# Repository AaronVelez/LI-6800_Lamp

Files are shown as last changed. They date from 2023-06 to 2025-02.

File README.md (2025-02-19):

# Hardware, software and data repository associated with “Open-source LED lamp for the LI-6800 photosynthesis system” paper.

&nbsp;
## Description
This repository contains the hardware CAD files, electronic schematics, software and data associated with an open-source LED lamp for the LI-6800 photosynthesis system. The full details on the lamp design, construction and calibration can be found in the associated paper. The paper is currently under review by the editorial office of the [Applications in Plant Science](https://bsapubs.onlinelibrary.wiley.com/journal/21680450) journal from the [Botanical Society of America](https://cms.botany.org/home.html).

&nbsp;
## Releases
|  Release |  Description |  Release date |
|  --- | --- | --- |
|  v1.0.0-beta.0 |  State of the repository at paper submission |  28 / Sep / 2023 |
|  v1.0.0-beta.1 |  State of the repository at paper resubmission | 23 / Apr / 2024 |
|  v1.0.0 | State of the repository at paper publication | 19 / Feb / 2025 |

&nbsp;
## Hardware
The content of this section is released under a [CERN Open Hardware Licence Version 2 - Weakly Reciprocal variant](Hardware/LICENSE). It has the following contents:

- AutoCAD Inventor files directory. It contains the 3D files of all individual parts as well as the final assembly in AutoCAD Inventor format.
- Ready-to-Print STL files directory. It contains the 3D-printable parts in STL format.
- STEP files directory. It contains the 3D files of all individual parts in STEP format.
- COB-LED driver Schematics.pdf file. Detailed electronic schematics.

&nbsp;
## Software
The content of this section is released under a [GNU Lesser General Public License Version 3](Software/LISENSE.LESSER). It has the following contents:

- Lamp folder. Software directly related with the Lamp function
  - A-PPFD_Curve.py file. An LI-6800 background program (a script in python) that performs an A-PPFD curve automatically.
  - LI-6800 Lamp Config File. A custom LI-6800 configuration file.
  - Microcontroller_Main.py file. A python script run by the Lamp internal microcontroller board.
  - PAR_Ctrl.py and PAR_Ctrl_wFB.py files. Two LI-6800 background program (a script in python) that control the light intensity in response to the desired PPFD entered by a user.

- Tools folder. Software tools used during lamp calibration and/or characterization
  - Curve_Fit_Zener_Diode.py file. A python script needed in the Lamp temperature control calibration.
  - Zenner Diode Calibration_Data Template.xlsx file. A Microsoft Excel file that serves as a data template for the Curve_Fit_Zener_Diode.py file
  - Homogenity_Scan_LabVIEW_VIs folder. A collection of LabVIEW VIs used to control a CNC machine in order to sacan the leaf area illuminated by the lamo with the objective of measuring the light homogenity
  - Homogenity_Scan_Python. Scripts used to process the RAW data measured with the LabVEW VIs

&nbsp;
## Data

- A-PPDF_Curves folder. This section contains the gas exchange data associated with the paper in a format that follows the recommendations of [Ely *et al.* (2021)]( https://doi.org/10.1016/j.ecoinf.2021.101232). The file [LI-6800_Lamp_Data_Description.pdf](Data/LI-6800_Lamp_Data_Description.pdf) holds a detailed description of all shared data files.
- Homogenity_Scans folder. This section contains the RAW measurements of the homogenity scans performed with the CNC machine.

&nbsp;
## Troubleshooting
|  Problem |  Possible reason |  Solution |
|  --- | --- | --- |
|  Fan and COB-LED do not turn ON |  External power supply is not connected | Make sure the external, 24V power supply is connected to the back of the lamp housing. |
|  At the LI-6800 console, Lamp_T shows values unexpectedly high (e.g. >100 °C), and Lamp_T_TH-r shows values close to 0 kohms |  The microcontroller is not exciting the thermistor with the required 3.3V |  At the LI-6800 console, navigate to the Console User I/O and turn ON the 5V power supply (Power5) |
|  At the LI-6800 console, the Q<sub>amb_in</sub> PPFD value is higher than the value measured with an external quantum sensor  | The Photodiode multiplier needs calibration  | Calibrate the photodiode multiplier following instructions in Appendix 2 |
|  The COB-LED dimly glows even if the DAC1 voltage is set to 0V  |  The zero offset of the XTR110 chip is not properly adjusted  |  Adjust the zero offset of the XTR110 chip by following the instructions in Appendix 2  |

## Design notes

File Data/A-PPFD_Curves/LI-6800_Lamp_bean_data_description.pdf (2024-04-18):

# Open-source LED lamp for the LI-6800 photosynthesis system

### Summary

In this work, a cost-effective lamp compatible with the LI-6800 photosynthesis measuring system was developed. The lamp uses a LED, emitting white light with a color temperature similar to sunlight. To demonstrate the functionality of the lamp, measurements of the response of photosynthesis to irradiance were made using PINTO SALTILLO bean line in 2024. In addition, some photosynthetic parameters were estimated form these measurements according to Busch et al. (2024).

The data described in this text is available on:

https://github.com/AaronVelez/LI-6800_Lamp/tree/main/Data

### Data Files

Data files:
LI-6800_Lamp_Bean_AQ_curves.csv
LI-6800_Lamp_ Bean_AQ_fittedparams.csv LI-6800_Lamp_ Bean_AQ_curves_InstrumentOutput.csv

Methods and metadata files:
LI-6800_Lamp_ Bean_methods_AQcurves.csv LI-6800_Lamp_ Bean_methods_AQparams.csv
LI-6800_Lamp_ Bean_instrumentDetails.csv

Data and methods files are in the format according the recommendations of Ely et al. (2021), following the example of Rogers et al. (2019)

### Data characteristics

Location | Escuela Nacional de Estudios Superiores Unidad León, León, Guanajuato, México
Latitude | 21.04
Longitude | 101.67
Altitude | 1.787 m ASL
Date from | 2024-03-21
Date to | 2024-03-22

### Data dictionaries

LI-6800_Lamp_ Bean_AQ_curves.csv
Number of records: 50
Header | Format | Units | Definition
USDA_Species_Code | Alphanumeric string | - | Code to identify the plant species used in measurements according the USDA
Sample_ID | Alphanumeric string | - | Identifier used for each sample
Date | Integer | YYYYMMDD | Date of observations
Time | HH:MM:SS | HH:MM:SS | Time of observations, set to local time (UTC-6)
A | Float | μmol m-2 s-1 | CO2 assimilation rate per leaf area
Ci | Float | µmol mol⁻¹ | Intercellular CO₂ concentration
CO2_S | Float | µmol mol⁻¹ | CO₂ concentration in air inside chamber
Patm | Float | kPa | Atmospheric pressure
Qin | Float | μmol m-2 s-1 | In-chamber photosynthetic flux density (PPFD) incident on the leaf, quanta per area
RHs | Float | % | Relative humidity of air inside the chamber
Tleaf | Float | °C | Leaf surface temperature

LI-6800_Lamp_ Bean_AQ_fittedparams.csv
Number of records: 5
Header | Format | Units | Definition
USDA_Species_Code | Alphanumeric string | - | Code to identify the plant species used in measurements according the USDA
Sample_ID | Alphanumeric string | - | Identifier used for each sample
Date | Integer | YYYYMMDD | Date of observations
Phi_CO2 | Float | - | Quantum efficiency of CO2 assimilation
A_Sat | Float | μmol m-2 s-1 | Light saturated CO2 assimilation rate

Rd | Float | μmol m-2 s-1 | Dark respiration rate derived only from the light response curve
Theta | Float | - | Empirical curvature factor of the response of CO2 assimilation to the light
I_comp | Float | μmol m-2 s-1 | Light compensation point

LI-6800_Lamp_ Bean_AQ_curves_InstrumentOutput.csv
Number of records: 50
This file is the output file obtained from the LI-6800 photosynthesis measuring system. The user definitions constants and variables are only described in the following table. The rest of the definitions for the other variables can be obtained from the LI-6800 under Start Up > Data Dictionary.
Header | Format | Units | Definition
Lamp_PAR_Ctrl | Float | μmol m-2 s-1 | Lamp desired PAR setpoint
Lamp_T_Ctrl | Float | °C | Lamp temperature setpoint
Lamp_Qamb_in_Factor | Float | - | Lamp mismatch factor between Qamb_in and Lamp_PAR_Ctrl
Lamp_T_trinket_V_Ctrl | Float | V | Lamp input Trinket voltage
Lamp_T_DAC2_V_Ctrl | Float | V | Lamp output Li-6800 voltage from auxiliary channel 2
Lamp_T_TH-r | Float | kohms | Lamp thermistor resistance. Measurement ADC_CH1 to thermistor resistance
Lamp_T | Float | °C | Lamp temperature. Measurement thermistor temperature to thermistor resistance
Lamp_PAR_DAC1_Ctrl | Float | V | Lamp output Li-6800 voltage to obtain the desired PAR setpoint

Example Data Records:

LI-6800_Lamp_ Bean_AQ_curves.csv

LI-6800_Lamp_ Bean_AQ_fittedparams.csv

USDA_Species_Code | Sample_ID | Date | Time A | Ci | CO2_s Patm Qin | RHs
Tleaf
- | - | YYYYMMDD | HH:MM:SS | μmol m-2 s-1 μmol mol-1 | μmol mol-1 | kPa
μmol m-2 s-1 % | °C
PHVU Bean1 20240322 | 14:36:54 | -1.613576991 400.2670327 400.09 82.0933
-0.154137 | 56.98042611 25.0162
PHVU Bean1 20240322 | 14:48:09 | 0.948748533 376.0389014 400.03 82.0997
40.0629 | 59.65035529 25.0068
USDA_Species_Code | Sample_ID | Date | Phi_CO2 | A_sat Rd | Theta I_comp
- | - | YYYYMMDD | - | μmol m-2 s-1 μmol m-2 s-1 - | μmol m-2 s-1
PHVU Bean1 20240322 | 0.060596005 19.36587742 1.536771248 0.78112109
25.80142873

PHVU Bean2 20240321 0.053367097 20.55056813 1.426724917 0.867451499 26.98018061

LI-6800_Lamp_ Bean_AQ_curves_InstrumentOutput.csv

USDA_Species_Code | Sample_ID | obs | time | elapseddate | hhmmss | averaging
Lamp_PAR_Ctrl Lamp_T_Ctrl | Lamp_Qamb_in_Factor Lamp_T_trinket_V_Ctrl
Lamp_T_DAC2_V_Ctrl Lamp_T_TH-r Lamp_TLamp_PAR_DAC1_Ctrl TIME E
Emm A | Ca | Ci | Pci | Pca | gsw | gbw | gtw | gtc | Rabs
TleafEB TleafCnd | SVPleaf RHcham | VPcham | SVPcham | VPDleaf
LatHFlux | SenHFlux | NetTherm | EBSum Leak | LeakPctCorrFact
CorrFactPct | Fan | Qin | Qabs alpha convertS | K | Geometry
CustomTIME CO2_s CO2_r H2O_s H2O_r CO2_a H2O_a Flow | Pa | ΔPcham
Tair | Tleaf Tleaf2 Offset Offset2 Fan_speed | Qamb_in | Qamb_out
ΔCO2 CO2_s_d | CO2_r_d | ΔH2O CO2_b H2O_b e_s | e_r | Td_s
Td_r | time | hhmmss | co2_t h2o_t count co2_adjh2o_adj | co2_match
h2o_match | co2_at h2o_at co2_cv h2o_cv CO2_r:MN | CO2_r:SLP | CO2_r:SD
CO2_r:OK | CO2_s:MN | CO2_s:SLP | CO2_s:SD | CO2_s:OK | H2O_s:MN
H2O_s:SLP | H2O_s:SD | H2O_s:OK | Stable Total State Vflow VPchamber
abs_c_a | abs_c_b | abs_h_a | abs_h_b | Wc_s Wc_r Wco_s
Wco_r Ww_s Ww_r Wwo_s Wwo_r Flow_s_v | Flow_r_v | Tleaf_mv
Tleaf2_mv | Tleaf_j Tleaf2_j | Console_RH | Console_T | Console_H2O
Fan_% Flow_%Pump Tchp_pwm | Txchg_pwm | diag_20v | diag_5_4v
diag_12v | diag_5va | diag_3_3vf | AccCO2_soda CO2_hrs
AccH2O_des | AccH2O_hum ADC_CH1 | ADC_CH2 | ADC_CH3 | ADC_CH4
ADC_CH5 | ADC_CH6 | ADC_CH7 | ADC_CH8 | DAC_1 DAC_2 DAC_3
DAC_4 GPIO GPIO_dir | excit_5v | power_12v | power_5v | ch1_pullup
AuxPower | MatchValveR MatchValveS MatchCO2 | MatchH2O | cf_co2_a
cf_co2_b | cf_co2_c | cf_co2_d | cf_h2o_a | cf_h2o_b | cf_h2o_c
cf_h2o_d | co2_fit_low | co2_fit_high | h2o_fit_low | h2o_fit_high
co2_elapsed | h2o_elapsed | CO2_f CO2_f_s | Pump_fPump_f_s | Pump_p
Pump_p_s | Tboard V_system | DIAG Flow_s Flow_r Txchg Tirga Tchopper
Ts | Tr | CO2_% Desiccant_% | Humidifier_% Txchg_sp | CO2_r_sp
H2O_r_sp | SS_s | SS_r

- | - | s | s | s | umol m^-2 s^-1 | °C
V | V | kohms °C | V | s | mol m?² s?¹ | mmol m?²
s?¹ | µmol m?² s?¹ µmol mol?¹ | µmol mol?¹ | Pa | Pa | mol m?² s?¹ | mol
m?² s?¹ mol m?² s?¹ | mol m?² s?¹ | W m?² °C | °C | kPa | % | kPa | kPa
kPa | W m?² W m?² W m?² W m?² µmol s?¹ | % | %
µmol s?¹ | µmol m?² s?¹ µmol m?² s?¹ | J/µmol cm²
mol m?² s?¹ | s | µmol mol?¹ | µmol mol?¹ | mmol mol?¹ | mmol mol?¹
µmol mol?¹ | mmol mol?¹ | µmol s?¹ | kPa | kPa | °C | °C | °C
°C | °C | rpm | µmol m?² s?¹ µmol m?² s?¹ µmol mol?¹ | µmol mol?¹
µmol mol?¹ | mmol mol?¹ | µmol mol?¹ | mmol mol?¹ | kPa | kPa | °C
°C | secs | s | s | µmol/mol | mmol/mol
µmol/mol | mmol/mol | µmol/mol | mmol/mol | % | %
µmol mol?¹ | µmol mol?¹ min?¹ | µmol mol?¹ | µmol mol?¹
µmol mol?¹ min?¹ | µmol mol?¹ | mmol mol?¹ | mmol mol?¹ min?¹
mmol mol?¹ | V | V
| | | | | | | | | V | V
mV | mV | °C | °C | % | °C | mmol mol?¹ | % | %
V | V | V | V | V | V | V | mg | hrs | mg | mg
V | V | V | V | V | V | V | V | V | V | V
V | | | | | | | V | % | %
µmol/mol | mmol/mol | µmol/mol | mmol/mol
µmol mol?¹ | µmol mol?¹ | mmol mol?¹ | mmol mol?¹
min | min | V | V | V | V | V | V | °C | V
µmol s?¹ | µmol s?¹ | °C | °C | °C | °C | °C | % | %
% | °C | µmol mol?¹ | mmol mol?¹ | % | %

### Data Acquisition Materials and Methods

Instrument: LI-6800 photosynthesis measuring system.

The complete methods for the the light response curve is available in: https://github.com/AaronVelez/LI-6800_Lamp/blob/main/Software/A-PPFD_Curve.py

PHVU Bean1 1 | 1711139814 | 0 | 20240322 14:36:54 | 14:36:54
none 0 | 30 | 1.053759919 1.2375 0 | 11.39255724 0
1.29E-15 | 1711139814 | 0.003958952 3.958951528 -1.613576991
400.09 400.2670327 32.87922316 32.86468113 0.278661499 2.506067093 0.262520691 0.165447657 -0.030056715 24.53932705 24.53932705 3.093388986 56.98042611 1.892218372 3.32082173 1.201170613 -174.5897624 160.9359103 13.60228033 -0.081628501 10
4 | 1 | 0 | 39382.31518 -0.154137 | -0.02466192 | 0.16
0.195 9 | 0.5 | 0: Broadleaf | 2 | 1711139814 | 400.09 399.993
23.0356 | 10.378 396.633 | 22.9076 | 275.011 | 82.0933
0.0499206 | 25.7305 | 25.0162 | 998.15 0 | -1.75 9007.5 -
0.154137 | 3.98461 | -0.0492554 | 409.362 | 404.187 | 12.6311
399.993 | 10.378 1.8889 0.851965 | 16.5425 | 4.60393
1711139855 | 14:37:35 | 1711139828 | 1711135652 | 69 | 0.147 0.01
3.457 0.128 400 | 24 | 0.46 | 0.02 | 400.0048167 0.057174215
0.109385174 1 | 399.9815 | -0.020112253 0.044482394 1
23.082865 | -0.09109347 | 0.027122874 1 | 3 | 3 | 03-mar
2.26976 | 2.68029 | 0.0756846 | 0.0758764 | 0.0914765
0.0501409 | 26883.7 | 24573 28473.2 | 25458.3 | 34919.7
33142.8 | 41749.9 | 37501.8 | 1.4789 1.54368 | 0.042282
0 | 24.3221 | 999.9 52.79 28.52 25.1515 | 47.8897
26.3341 | 0.5 | 0.259284 | -0.610289 | 20.3199 | 5.25862
11.9403 | 4.9953 3.299 9999 999.9 9999 9999 2.55533
1.87424 | 1.87332 | 1.87787 | 1.87621 | 1.87756
1.87173 | 1.87821 | 0 | 1.1658 0 | 0 | 11111010
oooooooo | off | off | on | off | 0 | 100 | 100 | 3.457
0.128 3.026929278 0.000723023 -1.21E-08 | -2.83E-11 | -
0.050759539 -0.013223211 0.001240205 -1.63E-05 | 2 | 2096 1 | 33
86.5 | 69.4 | 0.76416 | 2.55859 | 0.947266 | 2.11182
0.996094 | 2.2937 31.9365 | 24.035 18 | 239.854 | 267.864
26.6588 | 30.375 30 | 30.8131 | 30.837 15.2525 | 65.8587
0 | 26.6571 | 400.018 | 10.4006 | 98.1552 | 98.0901

### References

Ely, K. S., Rogers, A., Agarwal, D. A., Ainsworth, E. A., Albert, L. P., Ali, A., … Yang, D. (2021). A reporting format for leaf-level gas exchange data and metadata. Ecological Informatics, 61, 101232. https://doi.org/10.1016/j.ecoinf.2021.101232

Rogers, A., Serbin, S. P., Ely, K. S., & Wullschleger, S. D. (2019). Terrestrial biosphere models may overestimate Arctic CO2 assimilation if they do not account for decreased quantum yield and convexity at low temperature. New Phytologist, 223(1), 167–179. https://doi.org/10.1111/nph.15750

Busch, F. A., Ainsworth, E. A., Amtmann, A., Cavanagh, A. P., Driever, S. M., Ferguson, J. N., … Papanatsiou, M. (2024). A guide to photosynthetic gas exchange measurements: Fundamental principles, best practice and potential pitfalls. Plant Cell and Environment, 1–21. https://doi.org/10.1111/pce.14815

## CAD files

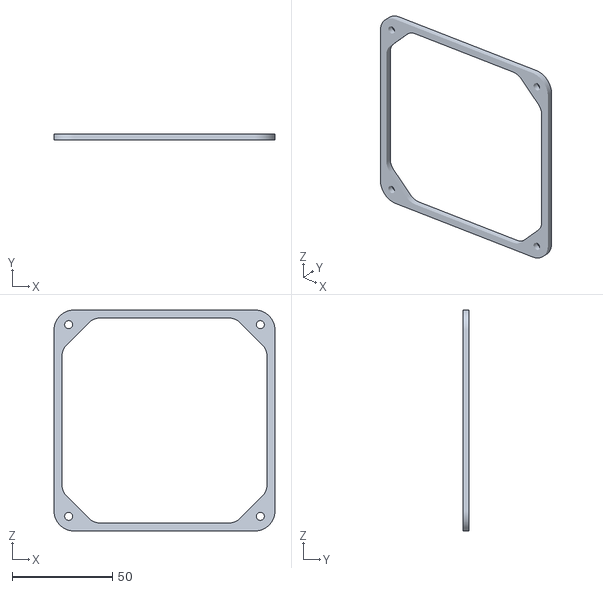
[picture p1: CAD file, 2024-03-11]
Hardware/Ready-to-Print STL files/Spacer.stl
110.4 x 3.20 x 110.4

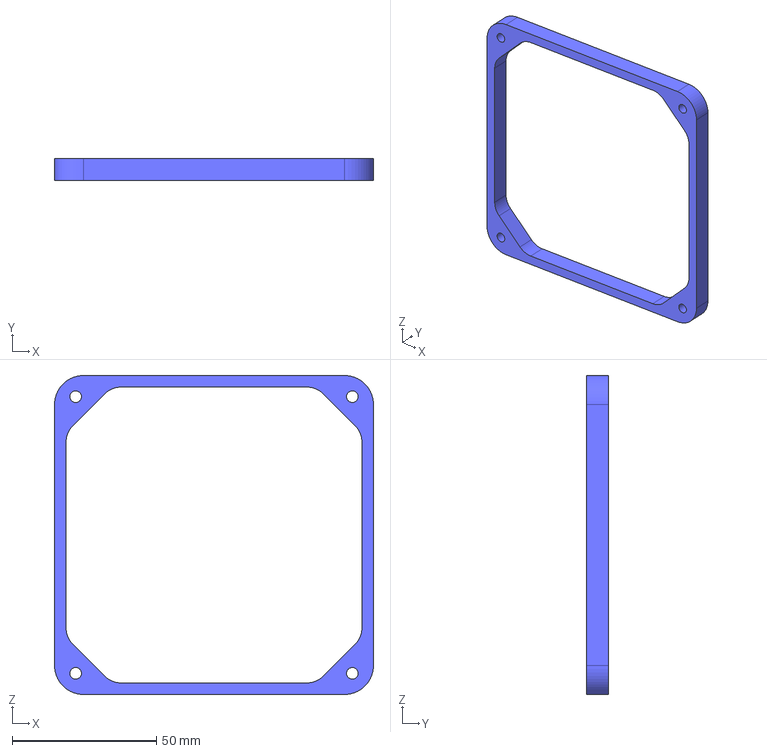
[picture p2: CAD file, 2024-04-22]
Hardware/STEP files/Spacer.stp
110.4 x 7.70 x 110.4 mm

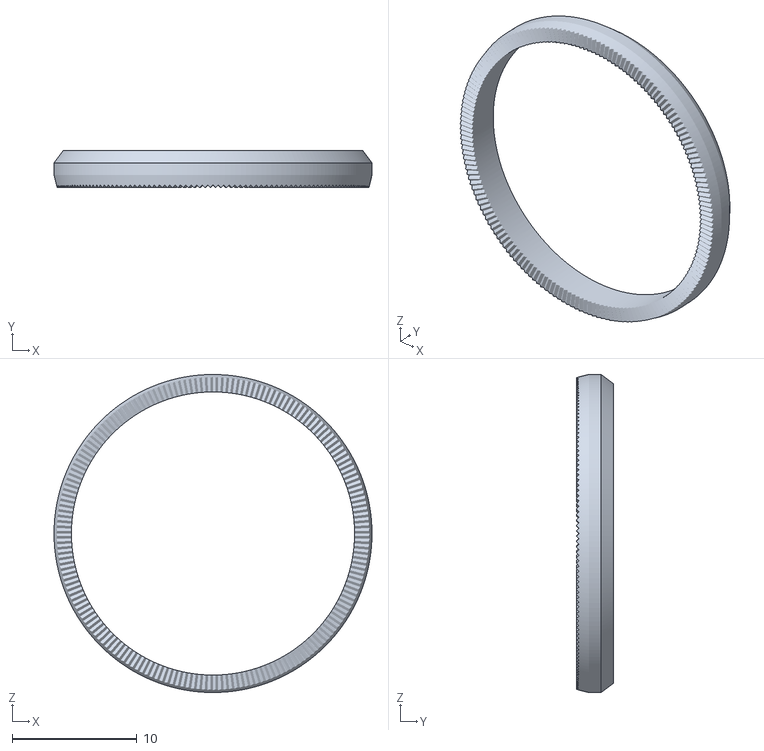
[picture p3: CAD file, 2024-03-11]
Hardware/Ready-to-Print STL files/Retaining ring.stl
25.5 x 3.00 x 25.5

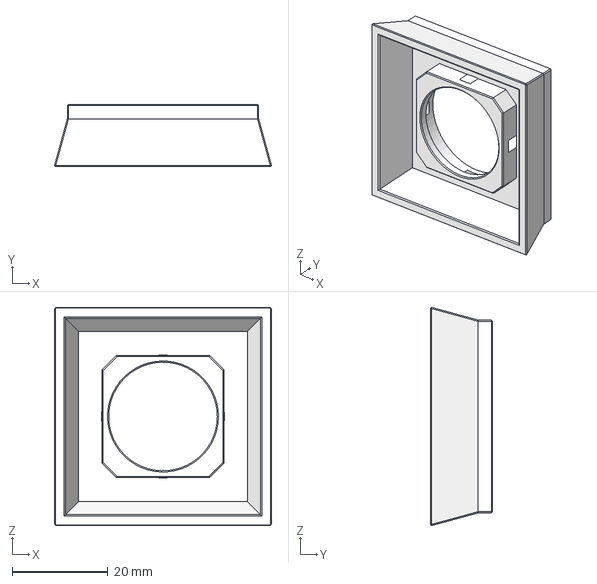
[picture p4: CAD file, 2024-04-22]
Hardware/STEP files/Filter Holder_25.4 mm.stp
45.4 x 13.0 x 45.6 mm

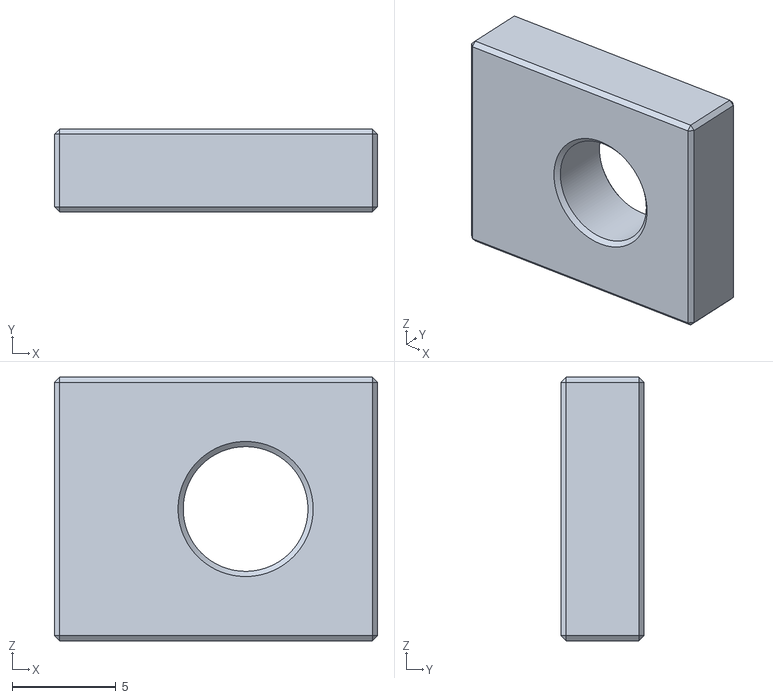
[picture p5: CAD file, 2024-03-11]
Hardware/Ready-to-Print STL files/Fan Shim.stl
15.5 x 4.00 x 12.7

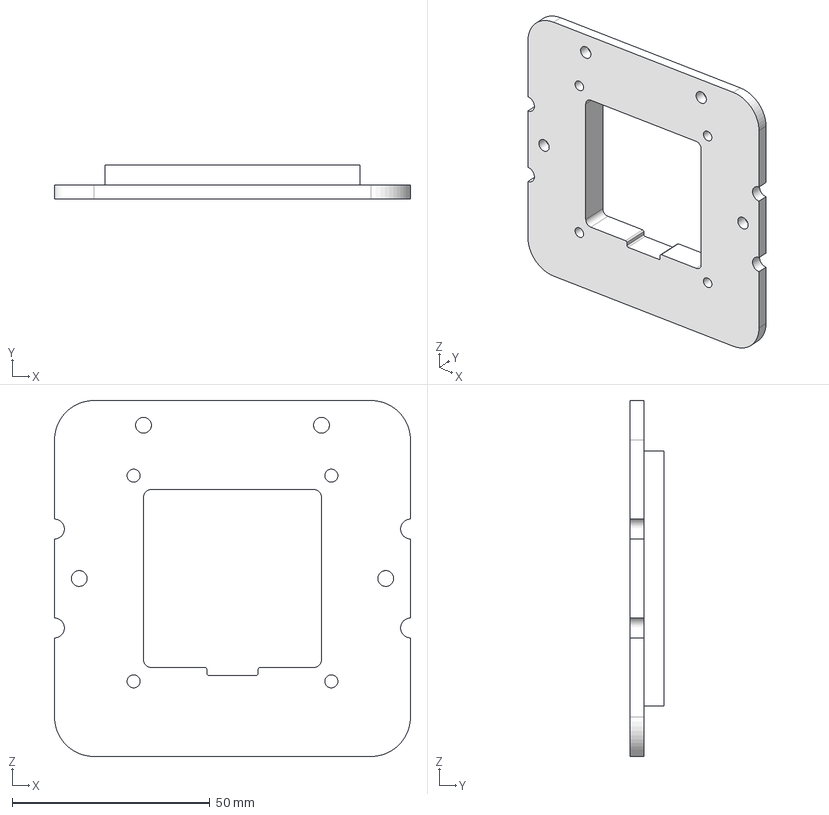
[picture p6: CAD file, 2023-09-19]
Hardware/STEP files/Lamp Holder.stp
90.0 x 8.50 x 90.0 mm

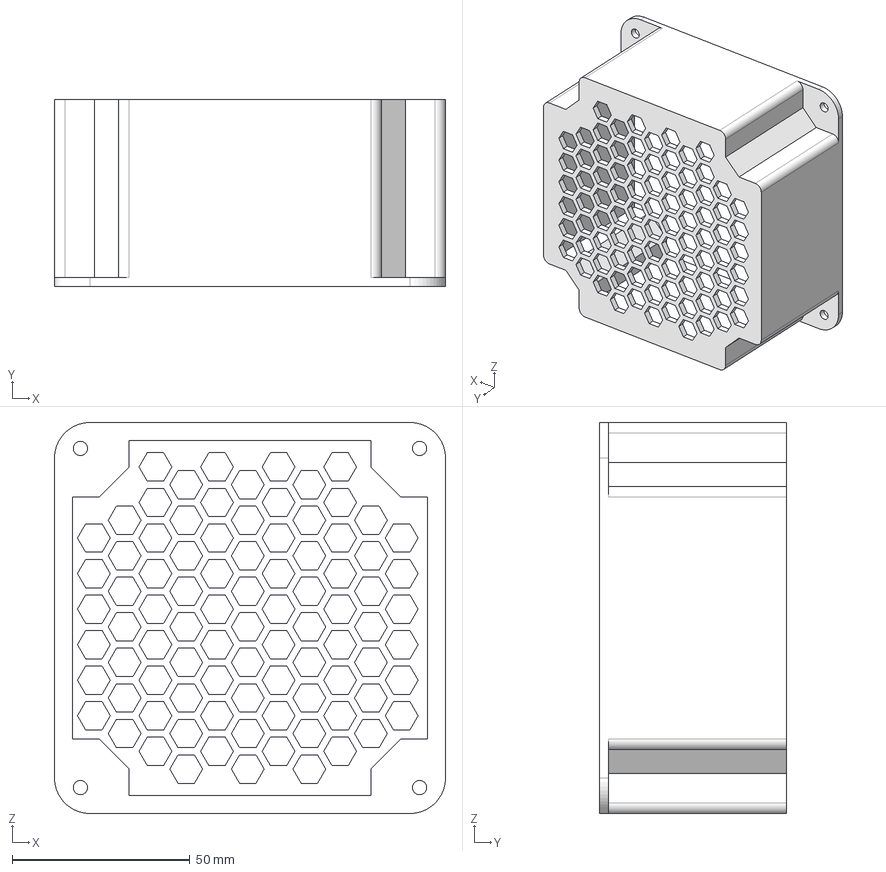
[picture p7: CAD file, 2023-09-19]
Hardware/STEP files/Fan Lid.stp
110.0 x 52.5 x 110.0 mm

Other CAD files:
Hardware/Ready-to-Print STL files/Filter Holder_25.4 mm.stl
Hardware/Ready-to-Print STL files/Fan Lid.stl
Hardware/Ready-to-Print STL files/Lamp Holder.stl
Hardware/AutoCAD Inventor files/BODY_N0016A_AF0.ipt
Hardware/AutoCAD Inventor files/Body.ipt
Hardware/AutoCAD Inventor files/CXA_1310N.ipt
Hardware/AutoCAD Inventor files/CXB1310-DIELECTRIC.ipt
Hardware/AutoCAD Inventor files/CXB1310-ENCAP.ipt
Hardware/AutoCAD Inventor files/CXB1310-LOGO.ipt
Hardware/AutoCAD Inventor files/CXB1310-POS.ipt
Hardware/AutoCAD Inventor files/CXB1310-ROUTING.ipt
Hardware/AutoCAD Inventor files/CXB1310-SM.ipt
Hardware/AutoCAD Inventor files/CXB1310-TM.ipt
Hardware/AutoCAD Inventor files/CXB1310.ipt
Hardware/AutoCAD Inventor files/Cable gland.ipt
Hardware/AutoCAD Inventor files/ED1-S20.ipt
Hardware/AutoCAD Inventor files/FQPF9P25.iam
Hardware/AutoCAD Inventor files/Fan Lid.ipt
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

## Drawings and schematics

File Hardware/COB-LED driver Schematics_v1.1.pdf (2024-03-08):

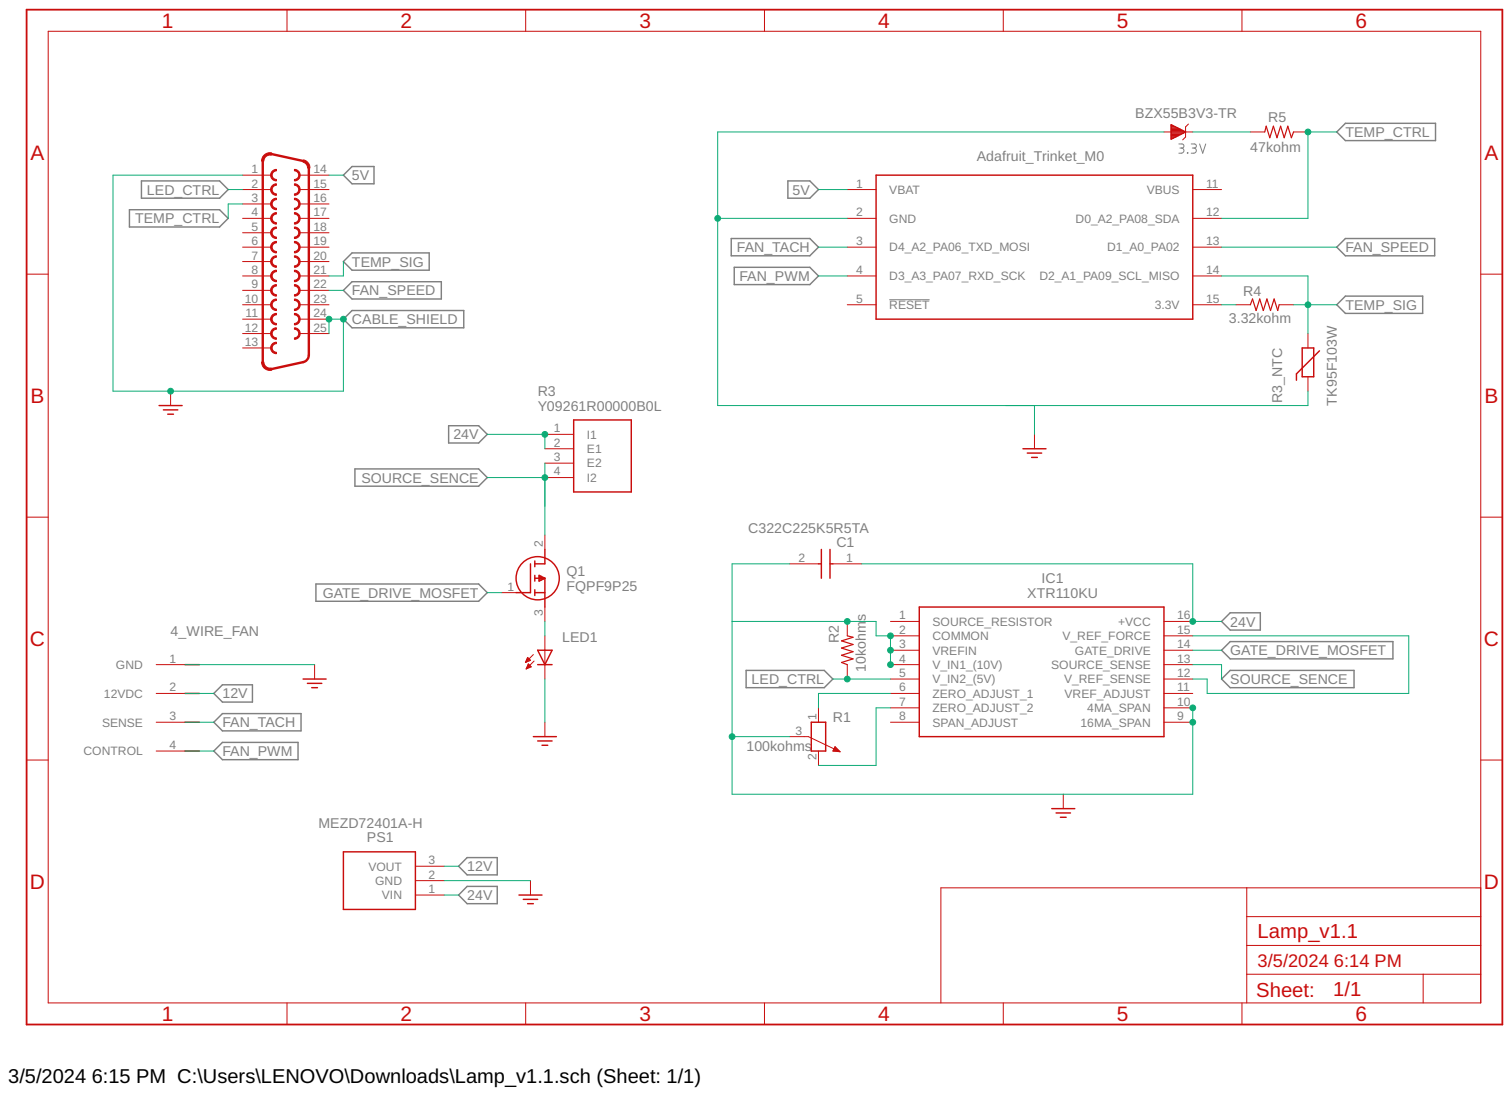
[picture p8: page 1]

3/5/2024 6:15 PM C:\Users\LENOVO\Downloads\Lamp_v1.1.sch (Sheet: 1/1)

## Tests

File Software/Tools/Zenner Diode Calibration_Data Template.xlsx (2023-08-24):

DAC2 | TEMP_CTRL_MCU | Modeled x (DAC2) | Error | Use Python script to find coefficients!
0.2 | 0.27122 | 0.2531348262 | 0.002823309756 | a | 12199
0.4 | 0.46454 | 0.4222424767 | 0.000494727771 | b | 147438769
0.6 | 0.654853 | 0.5945664868 | 2.952306516e-05 | c | 45440000
0.8 | 0.846931 | 0.7750378419 | 0.0006231093355 | d | 2272
1 | 1.03232 | 0.9562181467 | 0.001916850678
1.2 | 1.22863 | 1.156557222 | 0.001887274931
1.4 | 1.41448 | 1.355425375 | 0.00198689721
1.6 | 1.60318 | 1.567972774 | 0.001025743188
1.8 | 1.78457 | 1.784145013 | 0.0002513806129
2 | 1.9614 | 2.008239991 | 6.789745254e-05
2.2 | 2.12801 | 2.234004607 | 0.001156313285
2.4 | 2.24177 | 2.397993622 | 4.025552506e-06
2.6 | 2.41819 | 2.67195748 | 0.005177878876
2.8 | 2.53836 | 2.875745656 | 0.005737404378
3 | 2.6439 | 3.069570557 | 0.004840062469
3.2 | 2.73751 | 3.256312621 | 0.00317111125
3.4 | 2.81925 | 3.434056953 | 0.001159876049
3.6 | 2.89242 | 3.608318476 | 6.919703471e-05
3.7 | 2.92544 | 3.692880237 | 5.069103206e-05
3.8 | 2.95855 | 3.78219003 | 0.0003171950255
3.9 | 2.98993 | 3.871741403 | 0.0007985483147
4 | 3.0185 | 3.958207693 | 0.001746596894
4.1 | 3.04644 | 4.048229652 | 0.002680168881
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

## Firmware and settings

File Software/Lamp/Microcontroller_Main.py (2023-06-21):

# Name: main.py
# Created: 10/11/2020
# Authors: Juan de Dios Moreno González y Aarón I. Vélez Ramírez
# Universidad Nacional Autónoma de México
#
# Firmware version: 2.0
# 
# Code for temperature control of LI6800 custum LED lamp
#
# Details:
# Runs in an Adafruit Trinket board with an ARM Cortex M0+ processor
# It measures LED temperature using a thermistor and voltage divider
# It controls a 4-wire fan via a 25kHz PWM signal
# PWM duty cycle is set by a PID algorithm to control LED temperaure
# Temperature setpoint is encoded in an analog signal from LI6800 console
# Fan speed is read from fan tachometer
# Fan speed is encoded in an analog singal and sent to LI6800


##### Module imports
import board
import pulseio
import time
import math
from digitalio import DigitalInOut, Direction, Pull
from analogio import AnalogIn, AnalogOut


##### Pin definitions
# 4-wire fan PWM control pin
Fan_PWM_pin = pulseio.PWMOut(board.D3, frequency=25000, duty_cycle=0)

# 4-wire fan tachometer
Fan_Tach_pin = DigitalInOut(board.D4)
Fan_Tach_pin.direction = Direction.INPUT
Fan_Tach_pin.pull = Pull.UP

# Analog LED temperature setpoint
LED_Temp_Ctrl_pin = AnalogIn(board.A2)

# Analog LED temperature read
LED_Temp_pin = AnalogIn(board.A1)

# Analog fan speed
Fan_Speed_pin = AnalogOut(board.A0)



##### Constants definitions
# Reference voltge.
# The real board voltage might differ from the nominal 3.3V. For better measurements, enter thevalue measured with a calibrated multimeter.
Ref_voltage = 3.29
n = 100              # voltage is measured n times

# Fan parameters
############################################################
hall_threshold = 50        # Hall counts per rpm estimation event
rpm_hall = 2                # Hall counts per revolution
Fan_max_rpm = 3000 * 1.15    # Nominal max fan speed plus 15% tolerance

# LED temperature parameters.
# Minimum temperature is the intercept in a linear equation defining the relation between
# voltage and setpoint temperature.
# Parameters and equation must coincide with LI6800 programing.
Max_LED_Temp = 55   # Mapped to 1.22 volts (voltage after zener diode)
Min_LED_Temp = 15   # Mapped to 0 volts
Max_Zener_V = 3.3  # Maximum voltage allowed by zener diode

# Thermistor parameters
Nom_R = 10      # Nominal thermistor resistance in kohms at 25°C
Div_R = 3.32    # Value of the voltage divider resistor in kohms
# Manufacturer (Amphenol) constants for calculate termistor resistance of material type F
# https://www.amphenol-sensors.com/hubfs/Documents/AAS-913-318B-Temp-Resistance-Curves-091614-web.pdf
a = [3.3538646E-03, 2.56544090E-04, 1.9243889E-06, 1.0969244E-07]
b = [3.3540154E-03, 2.5627725E-04, 2.0829210E-06, 7.3002306E-08]
c = [3.3539264E-03, 2.5609446E-04, 1.9621987E-06, 4.6045930E-08]
d = [3.3368620E-03, 2.4057263E-04, -2.6687093E-06, -4.0719355E-07]

# PID gains and parameters
Kp = 20000
Ki = 1500
Kd = 375
MV_bar = 0
beta = 1
gamma = 0.1
MV_min = 21845
MV_max = 65535
N = 5



##### Variable definitions
Fan_PWM_duty_cycle_bits = 0     # In 16-bit format
Fan_Tach_rpm = 0
Fan_Tach_bits = 0               # In 16-bit format
LED_Temp_Ctrl_voltage = 0.0
LED_Temp_Ctrl_Cdeg = 0.0
LED_Temp_voltage = 0.0
LED_Temp_Cdeg =0.0



##### Functions
# PID function attributed to https://github.com/jckantor/CBE30338
def PID(Kp, Ki, Kd, MV_bar=0, MV_min=0, MV_max=65535, beta=1, gamma=0, N=5):
    # initialize stored data
    t_prev = -100
    P = 0
    I = 0
    D = 0
    S = 0

    # initial control
    MV = MV_bar

    while True:
        # yield MV, wait for new t, SP, PV, TR
        data = yield MV

        # see if a tracking data is being supplied
        if len(data) < 4:
            t, SP, PV = data
            # print("No TR")
        else:
            t, SP, PV, TR = data
            I = TR - MV_bar - P - D
            # print ('TR: {}'.format(TR))
            # print ('I_start: {}'.format(I))

        # PID calculations
        # print("PID calculation start")
        # print ('MVmax: {}'.format(MV_max))
        P = Kp*(beta*SP - PV)
        # print ('P: {}'.format(P))
        I = I + Ki*(SP - PV)*(t - t_prev)
        # print ('I: {}'.format(I))
        eD = gamma*SP - PV
        D = N*Kp*(Kd*eD - S)/(Kd + N*Kp*(t - t_prev))
        # print ('D: {}'.format(D))
        MV = MV_bar + P + I + D
        # print ('MVraw: {}'.format(MV))

        # Constrain MV to range MV_min to MV_max for anti-reset windup
        MV = MV_min if MV < MV_min else MV_max if MV > MV_max else MV
        # print ('MV: {}'.format(MV))
        I = MV - MV_bar - P - D

        # update stored data for next iteration
        S = D*(t - t_prev) + S
        t_prev = t



##### Setup
# Create and initialize PID control
PID_fan = PID(Kp, Ki, Kd, MV_bar, MV_min, MV_max, beta, gamma, N) # NEEDS TUNING!
PID_fan.send(None)



##### Main Loop
##### It runs forever
while True:
    # Step 1. Read LED temperature setpoin defined by LI6800.
    # print("\n")
    # print("Step 1 start")
    # 1.1 Read n times the analog voltage proportional to desired LED temperature at LED_Temp_Ctrl_pin
    sum = 0
    for x in range(n):
        sum += LED_Temp_Ctrl_pin.value
    mean = sum / n
    LED_Temp_Ctrl_voltage = (mean * Ref_voltage)/65535
    # print('LED Temp Ctrl voltage: {} volts'.format(LED_Temp_Ctrl_voltage))

    # 1.2 Convert it to °C using constant (needs to be added to constants) and store it in LED_Temp_Ctrl_Cdeg
    LED_Temp_Ctrl_Cdeg = Min_LED_Temp + (LED_Temp_Ctrl_voltage * ((Max_LED_Temp-Min_LED_Temp)/ Max_Zener_V))
    # print('LED Temp Ctrl Cdeg: {} °C'.format(LED_Temp_Ctrl_Cdeg))


    # Step 2. Read LED temperature
    # print("Step 2 start")
    # 2.1 Read analog voltage at LED_Temp_pin and store it in LED_Temp_voltage
    sum = 0
    for x in range(n):
        sum += LED_Temp_pin.value
    mean = sum / n
    LED_Temp_voltage = (mean * Ref_voltage)/65535
    # print('LED Temp voltage: {} volts'.format(LED_Temp_voltage))

    # 2.2 Translate read voltage to Thermistor resistance
    Thermistor_R = (LED_Temp_voltage*Div_R)/(Ref_voltage - LED_Temp_voltage)
    # print('Thermistor resistance: {} kohms'.format(Thermistor_R))                  ## Borrar este # print envetualmente.

    # 2.3 Translate thermistor resistance to LED temperature and store it in LED_Temp_Cdeg
    if Thermistor_R/Nom_R <= 68.6 and Thermistor_R/Nom_R > 3.274:         # -50 to 0 °C range
        LED_Temp_Cdeg = (1 / (a[0] +
                         (a[1]*math.log(Thermistor_R/Nom_R)) +
                         ((a[2]*math.log(Thermistor_R/Nom_R))**2) +
                         ((a[3]*math.log(Thermistor_R/Nom_R))**3) )) - 273.15
    elif Thermistor_R/Nom_R <= 3.274 and Thermistor_R/Nom_R > 0.36036:    # 0 to 50 °C range
        LED_Temp_Cdeg = (1 / (b[0] +
                         (b[1]*math.log(Thermistor_R/Nom_R)) +
                         ((b[2]*math.log(Thermistor_R/Nom_R))**2) +
                         ((b[3]*math.log(Thermistor_R/Nom_R))**3) )) - 273.15
    elif Thermistor_R/Nom_R <= 0.36036 and Thermistor_R/Nom_R > 0.06831:  # 50 to 100 °C range
        LED_Temp_Cdeg = (1 / (c[0] +
                         (c[1]*math.log(Thermistor_R/Nom_R)) +
                         ((c[2]*math.log(Thermistor_R/Nom_R))**2) +
                         ((c[3]*math.log(Thermistor_R/Nom_R))**3) )) - 273.15
    else:                                                                 # 100 to 150 °C range
        LED_Temp_Cdeg = (1 / (d[0] +
                         (d[1]*math.log(Thermistor_R/Nom_R)) +
                         ((d[2]*math.log(Thermistor_R/Nom_R))**2) +
                         ((d[3]*math.log(Thermistor_R/Nom_R))**3) )) - 273.15
    # print ('Temperature: {} °C'.format(LED_Temp_Cdeg))                            ## Borrar este # print envetualmente.
    # print((LED_Temp_Cdeg,))
    time.sleep(0.1)


    # Step 3. Read fan speed and send it to LI6800
    # print("Step 3 start")
    # 3.1 Read digital pulses at Fan_Tach_pin
    ########################################################################
    hall_count = 0
    on_state = False
    start = time.monotonic()
    while True:
        if Fan_Tach_pin.value == False:
            if on_state == False:
                on_state = True
                hall_count += 1
        else:
            on_state = False
        if hall_count >= hall_threshold:
            break
    end = time.monotonic()

    # 3.2 Calculate fan speed in rpm and store it in Fan_Tach_rpm
    Fan_Tach_rpm = ((hall_count / (end - start)) / rpm_hall) * 60
    # print ('Fan speed: {} rpm'.format(Fan_Tach_rpm))

    # 3.3 Convert Fan_Tach_rpm into a 16-bit value, mapping the maximum fan speed (Fan_max_rpm constant) to 65,536,
    # and store it in Fan_Tach_bits
    Fan_Tach_bits = (Fan_Tach_rpm * 65535) / Fan_max_rpm
    # print ('Fan speed: {} bits'.format(Fan_Tach_bits))

    # 3.4 Output FanTach_bits value to Fan_Speed_pin, so LI6800 can read it
    # AnalogOut.value acepts 16-bit values; so Fan_Tach_bits is mapped from 0 to 3.3 V by board
    Fan_Speed_pin.value = int(round(Fan_Tach_bits))



    # Step 4. Run PID control algorithm.
    # print("Step 4 start")
    # It calculates the required fan speed (in PWM duty cycle values IN 16-bit format) to achive the desired LED temperature.
    # It takes into consideration the current and near past LED temperature.
    t = time.monotonic()
    PV = LED_Temp_Cdeg
    SP = LED_Temp_Ctrl_Cdeg
    #SP = 28     # Override for debugging
    #TR = Fan_Tach_bits
    # Given time (t) process variable (PV), setpoint (SP) and tracked MV (TR), it returns manipulated variable (MV) and P, I, D and d
    MV = PID_fan.send([t, PV, SP])
    Fan_PWM_duty_cycle_bits = MV
    # print ('PID PWM control: {} %'.format(Fan_PWM_duty_cycle_bits*100/65535))


    # Step 5. Set new Fan speed
    # 5.1 Write to Fan_PWM_pin the new PWM duty cycle in 16-bit format (Fan_PWM_duty_cycle_bits) calculated by the PID algorithm
    Fan_PWM_pin.duty_cycle = int(round(Fan_PWM_duty_cycle_bits))

    # print('Time: {}'.format(time.monotonic()))

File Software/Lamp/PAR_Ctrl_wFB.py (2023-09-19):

from bpdefs import PROPERTIES, GROUP, ASSIGN, WHILE, IF, COMMENT, SHOW, SETCONTROL, ELIF, ELSE, WAIT, Nothing, CheckBox, Text, Button, DropDown, RadioBtns, EditBox, DataDict

steps=[
# Set program properties: PROPERTIES([verbose=False] [,pause=False])
PROPERTIES(verbose="False",pause="False"),
# Collection: GROUP(enabled, label)
GROUP("True","Define registers",
	steps=(
		# Assign a variable to an expression: ASSIGN('varname', exp="expression" [,dlg=Nothing()])
		ASSIGN("prev_DAC1",
			exp="0"),
		# Assign a variable to an expression: ASSIGN('varname', exp="expression" [,dlg=Nothing()])
		ASSIGN("Qin_factor",
			exp="1"),
		# Assign a variable to an expression: ASSIGN('varname', exp="expression" [,dlg=Nothing()])
		ASSIGN("FB_factor",
			exp="1"),
	)
),
# Loop while something is True: WHILE("bool_expression", [,var='elapsed_seconds'] [,mininc="secs"])
WHILE("True",
	steps=(
		# Collection: GROUP(enabled, label)
		GROUP("True","Update variables",
			steps=(
				# Assign a variable to a Data Dictionary entry: ASSIGN('varname', dd=DataDict('group', 'name' [,bool_logged]) [,track=False] [,optvar='varname'] [dlg=Nothing()))])
				ASSIGN("needed_DAC1",
					dd=DataDict('Lamp_PAR_DAC1_Ctrl','UserDefVar')),
				# Assign a variable to a Data Dictionary entry: ASSIGN('varname', dd=DataDict('group', 'name' [,bool_logged]) [,track=False] [,optvar='varname'] [dlg=Nothing()))])
				ASSIGN("PAR_set",
					dd=DataDict('Lamp_PAR_Ctrl','UserDefCon')),
				# Assign a variable to a Data Dictionary entry: ASSIGN('varname', dd=DataDict('group', 'name' [,bool_logged]) [,track=False] [,optvar='varname'] [dlg=Nothing()))])
				ASSIGN("PAR_real",
					dd=DataDict('PPFD_in','Meas')),
			)
		),
		IF("round(float(PAR_set), 4) > 0",
			steps=(
				IF("abs(1 - (prev_DAC1 / needed_DAC1)) >= 0.1",
					steps=(
						# Comment for ui: COMMENT(text)
						COMMENT("PAR change of more than 10%, preadjusting without FB factor "),
						# Print to run log: SHOW([items=(list of items)] or [string='string_to_print'])
						SHOW(string="'PAR change of more than 25%, pre-adjusting without FB factor'"),
						# Assign a variable to an expression: ASSIGN('varname', exp="expression" [,dlg=Nothing()])
						ASSIGN("FB_factor",
							exp="1"),
						# Set a control: SETCONTROL('target', 'value', 'eval' [,opt_target=''])
						SETCONTROL("Dac1","min(max(0, needed_DAC1), 5)","float"),
					)
				),
				ELIF("abs(1 - (float(PAR_set) / PAR_real)) >= 0.001",
					steps=(
						# Comment for ui: COMMENT(text)
						COMMENT("Difference between PAR_set and PAR_real of more than 0.1%, adjusting FB factor"),
						# Assign a variable to an expression: ASSIGN('varname', exp="expression" [,dlg=Nothing()])
						ASSIGN("Qin_factor",
							exp="(PAR_real / FB_factor) / float(PAR_set)"),
						# Set a control: SETCONTROL('target', 'value', 'eval' [,opt_target=''])
						SETCONTROL("User:Lamp_Qamb_in_Factor","Qin_factor","string"),
						# Assign a variable to an expression: ASSIGN('varname', exp="expression" [,dlg=Nothing()])
						ASSIGN("FB_factor",
							exp="1/Qin_factor"),
						# Set a control: SETCONTROL('target', 'value', 'eval' [,opt_target=''])
						SETCONTROL("Dac1","min(max(0, (needed_DAC1 * FB_factor)), 5)","float"),
					)
				),
				ELIF("round(needed_DAC1, 4) != prev_DAC1",
					steps=(
						# Comment for ui: COMMENT(text)
						COMMENT("Small change in needed DAC1, adjusting with current FB factor "),
						# Print to run log: SHOW([items=(list of items)] or [string='string_to_print'])
						SHOW(string="'Small change in needed DAC1, adjusting with current FB_factor'"),
						# Set a control: SETCONTROL('target', 'value', 'eval' [,opt_target=''])
						SETCONTROL("Dac1","min(max(0, (needed_DAC1 * FB_factor)), 5)","float"),
					)
				),
				# Assign a variable to an expression: ASSIGN('varname', exp="expression" [,dlg=Nothing()])
				ASSIGN("prev_DAC1",
					exp="round(needed_DAC1, 4)"),
			)
		),
		ELSE(steps=(
				# Set a control: SETCONTROL('target', 'value', 'eval' [,opt_target=''])
				SETCONTROL("Dac1","0","float"),
			)
		),
		# Wait for a time duration: WAIT(dur="float" [,units='Seconds' (Seconds|Minutes|Hours)])
		WAIT(dur="6",units="Seconds"),
	)
),
]

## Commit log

2023-06-21 Update main.py
    Weblink to the thermistor resistance-temperature curve document was added as note.
2023-08-24 Script to fit DAC2 vs TEMP_CTRL added
    [Zenner Diode Calibration_Data Template.xlsx]
2023-08-24 Bug fix in Excel Template
    [Zenner Diode Calibration_Data Template.xlsx]
2023-09-19 Upload Wheat A-PPFD curves.csv
    [Wheat A-PPFD curves.csv]
2023-09-19 Lamp Illustrator assembly added
    [Lamp v1.0.iam]
2023-09-19 Dependent assembly files added
    [BODY_N0016A_AF0.ipt, Body.ipt, CXA_1310N.ipt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]
2023-09-19 Ready-to-Print STL files added
    [Fan Lid.stl, Lamp Holder.stl]
2023-09-19 STEP files added
    [Fan Lid.stp, Lamp Holder.stp]
2023-09-20 Electronic schematics added
2023-09-28 Rename LI-6800_Lamp_AQ_curves_Instrument_output.csv
    [LI-6800_Lamp_AQ_curves_Instrument_output.csv]
2023-09-28 Rename to LI-6800_Lamp_AQ_fitted_params.csv
    [LI-6800_Lamp_AQ_fitted_params.csv]
2023-09-28 Rename to LI-6800_Lamp_instrument_details.csv
    [LI-6800_Lamp_instrument_details.csv]
2023-09-28 Rename to LI-6800_Lamp_AQ_curves_instrument_output.csv
    [LI-6800_Lamp_AQ_curves_instrument_output.csv]
2023-09-28 Rename to LI-6800_Lamp_methods_AQ_curves.csv
    [LI-6800_Lamp_methods_AQ_curves.csv]
2023-09-28 Rename to LI-6800_Lamp_methods_AQ_params.csv
    [LI-6800_Lamp_methods_AQ_params.csv]
2023-09-28 Rename directory to AutoCAD Inventor files
    [BODY_N0016A_AF0.ipt, Body.ipt, CXA_1310N.ipt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]
2024-03-08 Schematics Updated
    [COB-LED driver Schematics_v1.1.sch]
2024-03-11 New STL parts added
    [Fan Shim.stl, Filter Holder_25.4 mm.stl, Retaining ring.stl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]
2024-03-11 New CAD files added
    [ED1-S20.ipt, Fan Shim.ipt, Filter Holder_25.4 mm.ipt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]
2024-03-11 Lamp assembly update
2024-04-18 A-PPFD curve BP update
    Control over CO2S instead of CO2R
    Updated flow rates for bean plants (3x3 insert)
2024-04-18 Data files uploaded
    A-PPFD curves on bean plants
    [LI-6800_Lamp_Bean_methods_AQ_params.csv, LI-6800_Lamp_bean_AQ_curves.csv, LI-6800_Lamp_bean_AQ_curves_instrument_output.csv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]
2024-04-18 Update LI-6800 Lamp Config File
    New calibration coefficients to use ED1-S20 diffuser
2024-04-22 Homogenity data added
    [4-10-2024_11.48 AM_NA39_No_Diff_3x3_Mirror_Rep1_RAW.csv, 4-10-2024_5.13 PM_NA39_No_Diff_1x3SS_Mirror_Rep1_RAW.csv, 4-10-2024_6.14 PM_NA39_No_Diff_2x3SS_Mirror_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]
2024-04-22 LabVEW VIs added
    [Zenner Diode Calibration_Data Template.xlsx]
2024-04-22 STEP files added for new parts
    [Filter Holder_25.4 mm.stp, Spacer.stp]
